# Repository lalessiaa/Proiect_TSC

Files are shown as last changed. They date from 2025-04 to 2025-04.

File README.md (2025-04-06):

# Open book reader
Am proiectat un E-book reader, fiind construit in jurul microcontrolerului ESP32-C6, cu un incarcator USB-C si slot microSD.

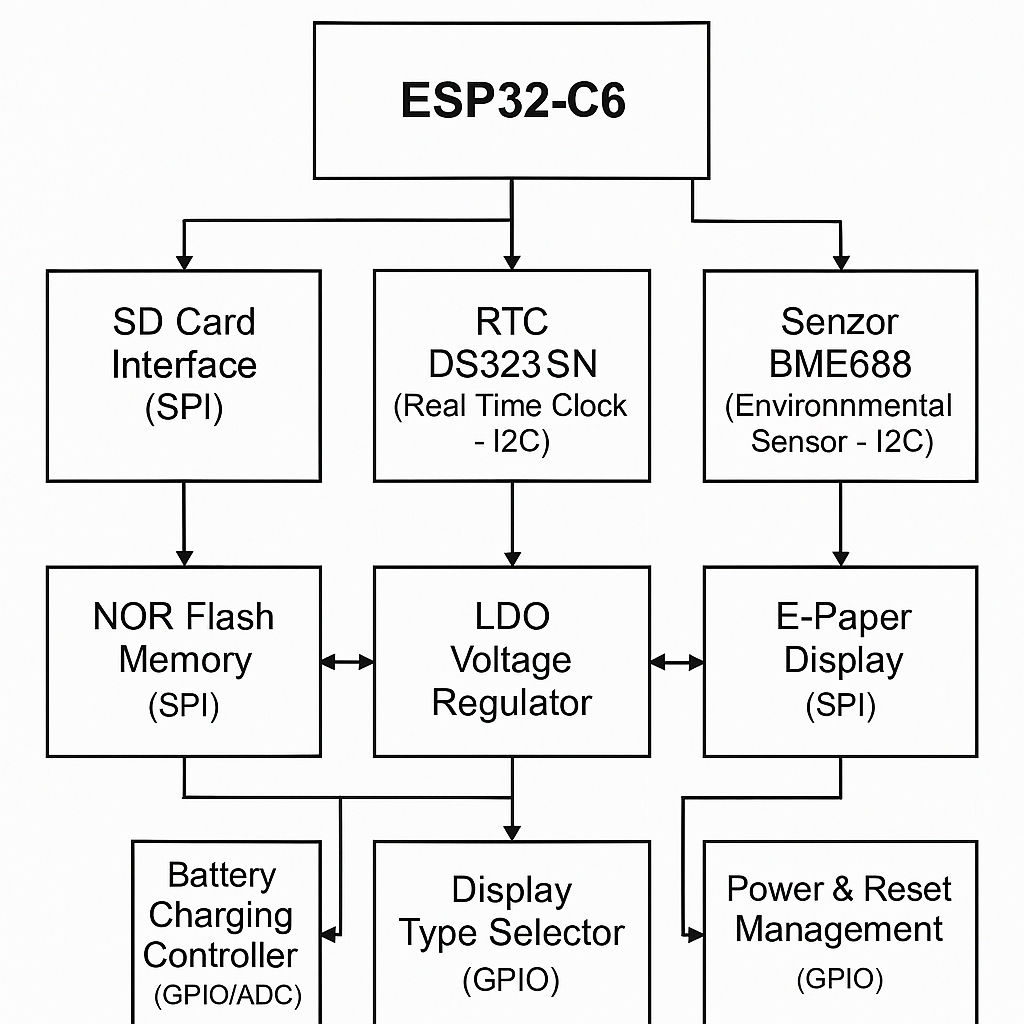
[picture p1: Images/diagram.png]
Diagrama openbook


Am urmat mai multi pasi in realizarea acestui poriect:
-	Crearea schematicului 
-	Am plasat componentele pe PCB
-	Am tras circuite si rutele
-	Incarcarea elementelor 3D pe PCB
-	Crearea bateriei si a display-ului
-	Inserarea bateriei, display-ului si a PCB-ului incarcasa 3D
  
# Functionalitati hardware
## ESP32-C6 
Este microcontroller-ul , el controleaza toate componentele si gestioneaza datele.
El foloseste mai multi pini printre care :
1)	Pentru comunicarea SPI cu viteza mare si numar redus de pini avem ( card SD ):   IO6 , IO7 (MOSI) , IO10 (CS) 
2)	Pentru a intra in mod de resetare rapida si mod de programare : IO0 - Buton BOOT , IO3 - Buton Reset
3)	External NOR Flash 64MB (SPI) pentru a extinde memoria: IO2 (MISO) , IO4 (CS) , IO6 (CLK/SCK) , IO7 (MOSI) 
4)	Battery Charge Level (GPIO) : IO12 

5)	Display Type Selector (GPIO): IO14

6)	Environmental Sensor BME688 (I2C) : IO8 (SCL), IO9 (SDA) 
7)	RTC Module DS3231SN (I2C) : IO8 (SCL) - linie de ceas I2C
IO9 (SDA) - linie de date I2C
8)	EPD Power (SPI) : IO6 (CLK/SCK), IO7 (MOSI), IO2 (MISO), IO5 (CS) 

1.	Senzorul de Mediu BME688
o	Interfață: I2C
o	Măsoară temperatura, umiditatea, presiunea, și compușii volatili organici pentru monitorizarea calității aerului.
2.	Memorie Externă NOR Flash 64MB
o	Interfață: SPI
o	Descriere: Folosită pentru stocarea datelor extinse și codului care nu se încadrează în memoria internă a ESP32.
o	Are consum redus în modul standby, crescând în timpul accesărilor de date.
3.	RTC (Real Time Clock) DS3231SN
o	Interfață: I2C
o	Menține timpul real chiar și în absența alimentării principale, utilizând o baterie de backup.
4.	Modulul de Încărcare a Bateriei
o	Interfață: GPIO (pentru monitorizarea stării)
o	Gestionează încărcarea bateriei Li-Po asigurând încărcare sigură și eficientă.
o	Are un consum mic, dependent de starea bateriei și de modul de încărcare.
5.	Regulator de Tensiune LDO
o	Regulează tensiunea de intrare pentru a asigura o alimentare stabilă de 3.3V pentru toate componentele.
Comunicații și Procesare
•	SPI: Utilizat pentru comunicații rapide cu memoria flash și display-ul E-Paper. Acest protocol este ideal pentru transferul de date la viteze înalte, esențial pentru performanța display-ului și accesul rapid la date.
•	I2C: Folosit pentru comunicația cu senzori de mediu și modulul RTC, care nu necesită viteze mari de transfer dar beneficiază de simplificarea conexiunilor.

# Bill of Materials
| Componenta | Link | Datasheet
| --- | --- |---|
|ESP32_WROVER_SPARKFUN-DISCRETESEMI_MOSFET_PCH-DMG2305UX-7|https://componentsearchengine.com/part-view/DMG2305UX-7/Diodes%20Incorporated|https://www.diodes.com//assets/Datasheets/DMG2305UX.pdf|
| QWIIC_CONNECTORJS-1MM | https://www.snapeda.com/parts/PRT-14417/SparkFun/view-part/ |https://www.snapeda.com/parts/PRT-14417/SparkFun%20Electronics/datasheet/
|CPH3225A|https://www.snapeda.com/parts/CPH3225A/Seiko+Instruments/view-part/?ref=eda|https://www.snapeda.com/parts/CPH3225A/Seiko%20Instruments/datasheet/|
|BUTTON_CUSYOMV1|https://industry.panasonic.com/global/en/downloads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|https://industry.panasonic.com/global/en/downloads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
|ESP32_WROVER_EAGLE-LTSPICE_CC0402|https://componentsearchengine.com/part-view/CC0402MRX5R5BB106/YAGEO|https://componentsearchengine.com/Datasheets/2/CC0402MRX5R5BB106.pdf
| ESP32_WROVER_EAGLE-LTSPICE_RR0402  | https://www.snapeda.com/parts/RC0402FR-07226RL/Yageo/view-part/ |https://www.snapeda.com/parts/RC0402FR-07226RL/Yageo/datasheet/
|BD5229G-TR|https://componentsearchengine.com/part-view/BD5229G-TR/ROHM%20Semiconductor|https://datasheet.datasheetarchive.com/originals/distributors/Datasheets_SAMA/f2b9741ef86007909f138d561a359946.pdf|
|DS3231SN|https://www.snapeda.com/parts/DS3231SN%23/Analog+Devices/view-part/?ref=eda|https://www.snapeda.com/parts/DS3231SN%23/Analog%20Devices/datasheet/|
|112A-TAAR-R03_ATTEND|https://store.comet.bg/en/Catalogue/Product/43497/|https://store.comet.bg/en/Catalogue/Product/43497/|
|744043680IND_4828-WE-TPC_WRE|https://www.digikey.sg/en/models/1638515|https://www.we-online.com/components/products/datasheet/744043680.pdf
|ESP32-C6-WROOM-1-N8|https://www.snapeda.com/parts/ESP32-C6-WROOM-1-N8/Espressif+Systems/view-part/?ref=eda|https://www.snapeda.com/parts/ESP32-C6-WROOM-1-N8/Espressif%20Systems/datasheet/
|ADAFRUIT_LEDCHIP-LED0603|https://www.snapeda.com/parts/KP-1608SURCK/Kingbright/view-part/?ref=search&t=LED%200603|https://www.snapeda.com/parts/KP-1608SURCK/Kingbright/datasheet/
|MCP73831|https://www.digikey.com/en/models/1874108|https://ww1.microchip.com/downloads/aemDocuments/documents/APID/ProductDocuments/DataSheets/MCP73831-Family-Data-Sheet-DS20001984H.pdf|
|XC6220A331MR-G|https://componentsearchengine.com/part-view/XC6220A331MR-G/Torex|https://product.torexsemi.com/system/files/series/xc6220.pdf|
|ESP32_WROVER_EAGLE-LTSPICE_CC0402|https://componentsearchengine.com/Datasheets/2/CC0402MRX5R5BB106.pdf|https://componentsearchengine.com/part-view/CC0402MRX5R5BB106/YAGEO|
|ESP32C6_VARISTORCN1812|https://www.mouser.co.uk/ProductDetail/EPCOS-TDK/B72520T0350K062?qs=dEfas%2FXlABIszF52uu7vrg%3D%3D|https://www.tdk-electronics.tdk.com/inf/75/db/CTVS_14/Surge_protection_series.pdf|
|MAX17048G+T10|https://www.snapeda.com/parts/MAX17048G+T10/Analog+Devices/view-part/?ref=eda|https://www.snapeda.com/parts/MAX17048G+T10/Analog%20Devices/datasheet/|
|PGB1010603MR|https://www.snapeda.com/parts/PGB1010603MR/Littelfuse/view-part/?ref=eda|https://www.snapeda.com/parts/PGB1010603MR/Littelfuse%20Inc./datasheet/|
|RCL_CPOL-EUCT3528|https://ro.mouser.com/ProductDetail/Vishay-Sprague/TR3B106K025C1300?qs=jCGqFXxTmLdffnuDkXzk1g%3D%3D|https://www.vishay.com/docs/40080/tr3.pdf|
|FH34SRJ-24S-0.5SH_99_|https://componentsearchengine.com/part-view/XC6220A331MR-G/Torex|https://product.torexsemi.com/system/files/series/xc6220.pdf|
|SAMACSYS_PARTS_USB4110-GF-A|https://componentsearchengine.com/part-view/USB4110-GF-A/GCT%20(GLOBAL%20CONNECTOR%20TECHNOLOGY)|https://gct.co/files/drawings/usb4110.pdf|
|SI1308EDL-T1-GE3|https://componentsearchengine.com/part-view/SI1308EDL-T1-GE3/Vishay|https://componentsearchengine.com/Datasheets/1/SI1308EDL-T1-GE3.pdf|
|MBR0530|https://ro.mouser.com/ProductDetail/KYOCERA-AVX/SD0805S020S1R0?qs=jCA%252BPfw4LHbpkAoSnwrdjw%3D%3D|https://ro.mouser.com/datasheet/2/40/schottky-3165252.pdf|
|SJ|https://grabcad.com/library/solder-jumpers-1||
|W25Q512JVEIQ|https://www.snapeda.com/parts/W25Q512JVEIQ/Winbond+Electronics/view-part/?ref=eda|https://www.snapeda.com/parts/W25Q512JVEIQ/Winbond%20Electronics/datasheet/|
|ESP32_WROVER_BME680_BME680|https://www.snapeda.com/parts/BME680/Bosch/view-part/?welcome=home|https://www.snapeda.com/parts/BME680/Bosch%20Sensortec/datasheet/|
|CPH3225A|https://www.snapeda.com/parts/CPH3225A/Seiko+Instruments/view-part/?ref=eda|https://www.snapeda.com/parts/CPH3225A/Seiko%20Instruments/datasheet/|
|USBLC6-2SC6Y|https://www.snapeda.com/parts/USBLC6-2SC6Y/STMicroelectronics/view-part/?ref=eda|https://www.snapeda.com/parts/USBLC6-2SC6Y/STMicroelectronics/datasheet/|

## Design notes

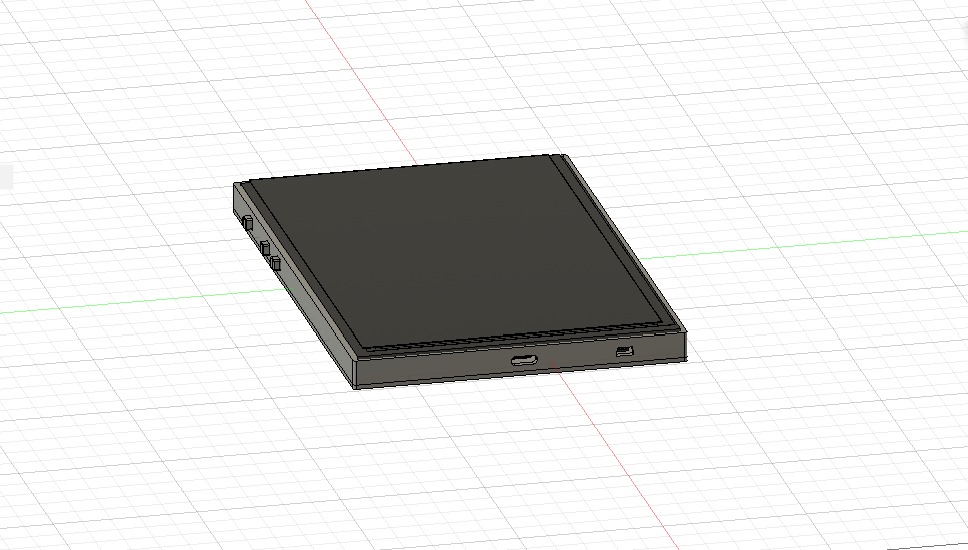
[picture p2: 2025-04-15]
Images/openbookdisplaynou.jpg

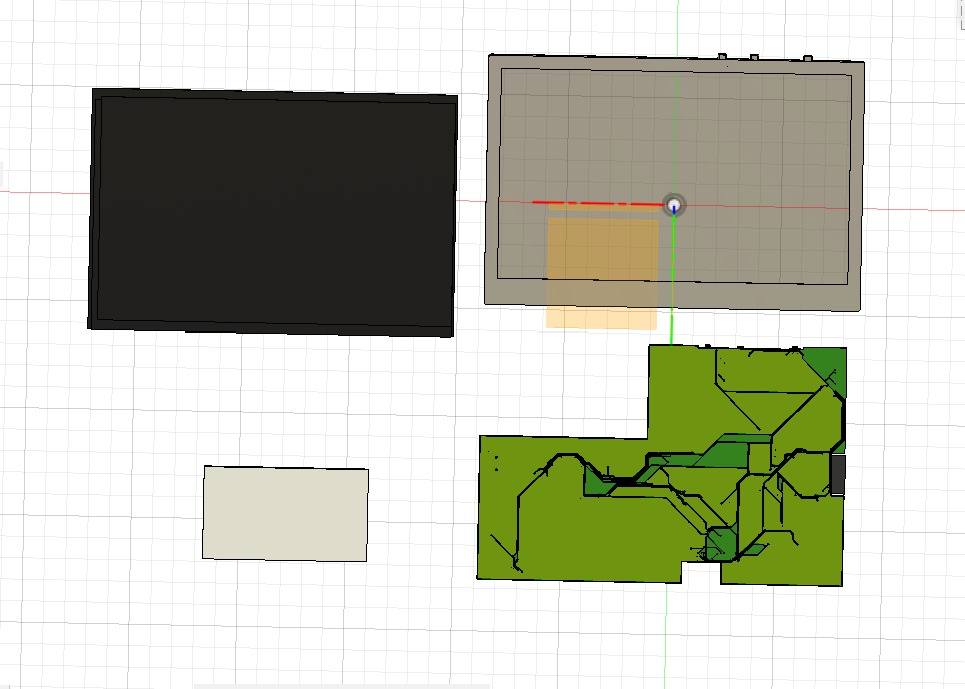
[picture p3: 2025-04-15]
Images/exploded_var_finala.jpg

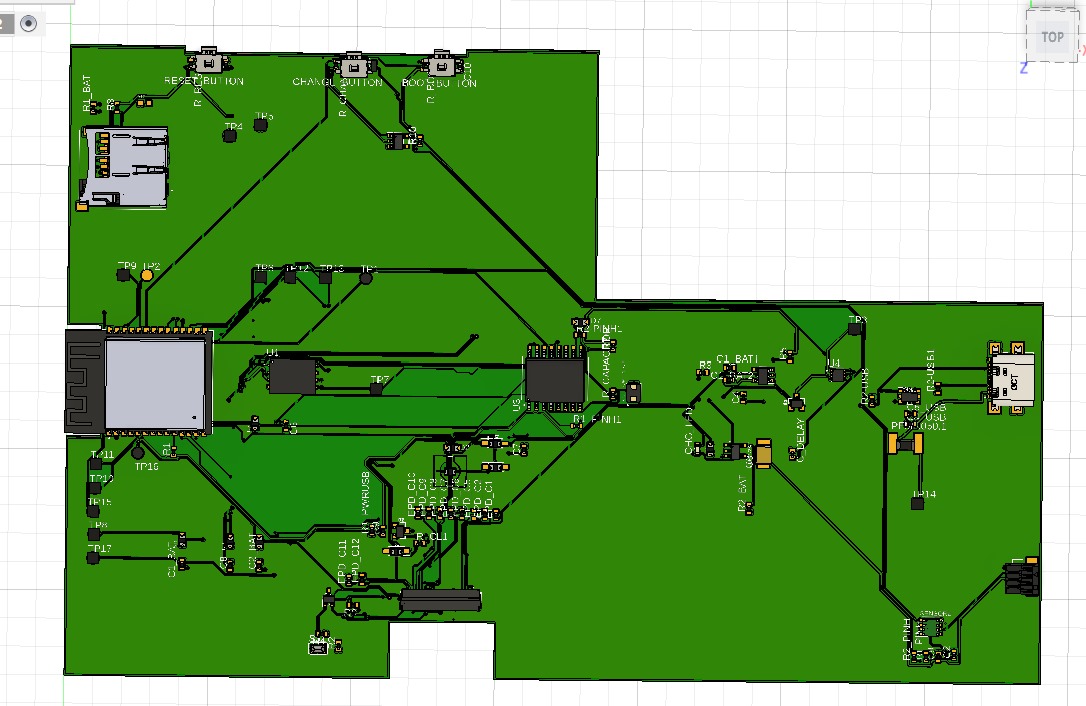
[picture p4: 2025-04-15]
Images/PCBvarfinala.jpg

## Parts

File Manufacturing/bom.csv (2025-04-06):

Qty | Value | Device | Package | Parts | Description | ARROW_PART_NUMBER | ARROW_PRICE-STOCK | AVAILABILITY | CENTROID_NOT_SPECIFIED | CHECK_PRICES | COPYRIGHT | DATASHEET | DESCRIPTION | DIGIKEY_DESCRIPTION | DIGIKEY_PART_NUMBER | HEIGHT | LEAD_FREE | MANUFACTURER_NAME | MANUFACTURER_PART_NUMBER | MF | MFR_NAME | MOUSER_PART_NUMBER | MOUSER_PRICE-STOCK | MOUSER_TESTING_PART_NUMBER | MOUSER_TESTING_PRICE-STOCK | MP | MPN | PACKAGE | POPULARITY | PREFIX | PRICE | PROD_ID | PURCHASE-URL | ROHS | SNAPEDA_LINK | SPICEMODEL | SPICEPREFIX | TEMPERATURE_RANGE_HIGH | TEMPERATURE_RANGE_LOW | TP_SIGNAL_NAME | VALUE
1 |  | ADAFRUIT_LEDCHIP-LED0603 | ADAFRUIT_CHIP-LED0603 | CHG_LED | LED
1 |  | SJ | SJ | SJ1 | SMD solder JUMPER |  |  |  |  |  |  |  |  |  |  |  |  |  |  |  |  |  |  |  |  |  |  |  | 3
1 | 0.47 | ESP32_WROVER_EAGLE-LTSPICE_RR0402 | ESP32_WROVER_EAGLE-LTSPICE_R0402 | R3 | RESISTOR, European symbol |  |  |  |  |  |  |  |  |  |  |  |  |  |  |  |  |  |  |  |  |  |  |  |  |  |  |  |  |  |  | NONE | R
1 | 01/Uf/50V | ESP32_WROVER_EAGLE-LTSPICE_CC0402 | ESP32_WROVER_EAGLE-LTSPICE_C0402 | EPD_C5 | CAPACITOR, European symbol |  |  |  |  |  |  |  |  |  |  |  |  |  |  |  |  |  |  |  |  |  |  |  |  |  |  |  |  |  |  | NONE | C
1 | 100k | ESP32_WROVER_EAGLE-LTSPICE_RR0402 | ESP32_WROVER_EAGLE-LTSPICE_R0402 | R1_PWRUSB | RESISTOR, European symbol |  |  |  |  |  |  |  |  |  |  |  |  |  |  |  |  |  |  |  |  |  |  |  |  |  |  |  |  |  |  | NONE | R
2 | 100nF | EAGLE-LTSPICE_CC0402 | EAGLE-LTSPICE_C0402 | C4_USB, C9 | CAPACITOR, European symbol |  |  |  |  |  |  |  |  |  |  |  |  |  |  |  |  |  |  |  |  |  |  |  |  |  |  |  |  |  |  | NONE | C
6 | 100nF | ESP32_WROVER_EAGLE-LTSPICE_CC0402 | ESP32_WROVER_EAGLE-LTSPICE_C0402 | C1, C2, C6, C8, C10, C_DELAY | CAPACITOR, European symbol |  |  |  |  |  |  |  |  |  |  |  |  |  |  |  |  |  |  |  |  |  |  |  |  |  |  |  |  |  |  | NONE | C
1 | 100uF TANT | RCL_CPOL-EUCT3528 | RCL_CT3528 | C3 | POLARIZED CAPACITOR, European symbol |  |  |  |  |  |  |  |  |  |  |  |  |  |  |  |  |  |  |  |  |  |  |  | 0 |  |  |  |  |  |  |  | C
7 | 10K | ESP32_WROVER_EAGLE-LTSPICE_RR0402 | ESP32_WROVER_EAGLE-LTSPICE_R0402 | R2_PINH, R4, RI_PINH, R_BOOT, R_CHANGE, R_CL1, R_RESET | RESISTOR, European symbol |  |  |  |  |  |  |  |  |  |  |  |  |  |  |  |  |  |  |  |  |  |  |  |  |  |  |  |  |  |  | NONE | R
9 | 10k | ESP32_WROVER_EAGLE-LTSPICE_RR0402 | ESP32_WROVER_EAGLE-LTSPICE_R0402 | R1, R1_PINH1, R2-PINH1, R5, R6, R7, R8, R9, R10 | RESISTOR, European symbol |  |  |  |  |  |  |  |  |  |  |  |  |  |  |  |  |  |  |  |  |  |  |  |  |  |  |  |  |  |  | NONE | R
1 | 10uF | ESP32_WROVER_EAGLE-LTSPICE_CC0402 | ESP32_WROVER_EAGLE-LTSPICE_C0402 | C7 | CAPACITOR, European symbol |  |  |  |  |  |  |  |  |  |  |  |  |  |  |  |  |  |  |  |  |  |  |  |  |  |  |  |  |  |  | NONE | C
1 | 112A-TAAR-R03_ATTEND | 112A-TAAR-R03_ATTEND | 112ATAARR03ATTEND | J4 | Micro SD Card Socket, Push-Push Type, Top Mount, SMT, H=1.83mm, 10u |  |  |  |  |  |  |  | Micro SD Card Socket | Push-Push Type | Top Mount | SMT | H=1.83mm | 10u |  |  | 1.9mm |  | ATTEND | 112A-TAAR-R03 ATTEND
1 | 15 | ESP32_WROVER_EAGLE-LTSPICE_RR0402 | ESP32_WROVER_EAGLE-LTSPICE_R0402 | R_CAPACITOR | RESISTOR, European symbol |  |  |  |  |  |  |  |  |  |  |  |  |  |  |  |  |  |  |  |  |  |  |  |  |  |  |  |  |  |  | NONE | R
1 | 1UF/50V | ESP32_WROVER_EAGLE-LTSPICE_CC0402 | ESP32_WROVER_EAGLE-LTSPICE_C0402 | EPD_C7 | CAPACITOR, European symbol |  |  |  |  |  |  |  |  |  |  |  |  |  |  |  |  |  |  |  |  |  |  |  |  |  |  |  |  |  |  | NONE | C
1 | 1Uf/50V | ESP32_WROVER_EAGLE-LTSPICE_CC0402 | ESP32_WROVER_EAGLE-LTSPICE_C0402 | EPD_C10 | CAPACITOR, European symbol |  |  |  |  |  |  |  |  |  |  |  |  |  |  |  |  |  |  |  |  |  |  |  |  |  |  |  |  |  |  | NONE | C
1 | 1uF | ESP32_WROVER_EAGLE-LTSPICE_CC0402 | ESP32_WROVER_EAGLE-LTSPICE_C0402 | C5 | CAPACITOR, European symbol |  |  |  |  |  |  |  |  |  |  |  |  |  |  |  |  |  |  |  |  |  |  |  |  |  |  |  |  |  |  | NONE | C
7 | 1uF/50V | ESP32_WROVER_EAGLE-LTSPICE_CC0402 | ESP32_WROVER_EAGLE-LTSPICE_C0402 | EPD_C1, EPD_C2, EPD_C6, EPD_C8, EPD_C9, EPD_C11, EPD_C12 | CAPACITOR, European symbol |  |  |  |  |  |  |  |  |  |  |  |  |  |  |  |  |  |  |  |  |  |  |  |  |  |  |  |  |  |  | NONE | C
1 | 2.2 | ESP32_WROVER_EAGLE-LTSPICE_RR0402 | ESP32_WROVER_EAGLE-LTSPICE_R0402 | R2 | RESISTOR, European symbol |  |  |  |  |  |  |  |  |  |  |  |  |  |  |  |  |  |  |  |  |  |  |  |  |  |  |  |  |  |  | NONE | R
1 | 200 | ESP32_WROVER_EAGLE-LTSPICE_RR0402 | ESP32_WROVER_EAGLE-LTSPICE_R0402 | R1_BAT | RESISTOR, European symbol |  |  |  |  |  |  |  |  |  |  |  |  |  |  |  |  |  |  |  |  |  |  |  |  |  |  |  |  |  |  | NONE | R
2 | 20V/4.2A/52mO/1.4W | ESP32_WROVER_SPARKFUN-DISCRETESEMI_MOSFET_PCH-DMG2305UX-7 | ESP32_WROVER_SPARKFUN-DISCRETESEMI_SOT23-3 | Q1, Q2 | P-channel MOSFETs |  |  |  |  |  |  |  |  |  |  |  |  |  |  |  |  |  |  |  |  |  |  |  |  |  |  | TRAN-14388 |  |  |  |  |  |  |  |  | 20V/4.2A/52mO/1.4W
1 | 2k | ESP32_WROVER_EAGLE-LTSPICE_RR0402 | ESP32_WROVER_EAGLE-LTSPICE_R0402 | R2_BAT | RESISTOR, European symbol |  |  |  |  |  |  |  |  |  |  |  |  |  |  |  |  |  |  |  |  |  |  |  |  |  |  |  |  |  |  | NONE | R
2 | 4.7uF | EAGLE-LTSPICE_CC0402 | EAGLE-LTSPICE_C0402 | C1_BAT1, C5_USB | CAPACITOR, European symbol |  |  |  |  |  |  |  |  |  |  |  |  |  |  |  |  |  |  |  |  |  |  |  |  |  |  |  |  |  |  | NONE | C
3 | 4.7uF | ESP32_WROVER_EAGLE-LTSPICE_CC0402 | ESP32_WROVER_EAGLE-LTSPICE_C0402 | C1_BAT, C1_BAT2, C2_BAT | CAPACITOR, European symbol |  |  |  |  |  |  |  |  |  |  |  |  |  |  |  |  |  |  |  |  |  |  |  |  |  |  |  |  |  |  | NONE | C
1 | 4.7uF/25V | ESP32_WROVER_EAGLE-LTSPICE_CC0402 | ESP32_WROVER_EAGLE-LTSPICE_C0402 | C4 | CAPACITOR, European symbol |  |  |  |  |  |  |  |  |  |  |  |  |  |  |  |  |  |  |  |  |  |  |  |  |  |  |  |  |  |  | NONE | C
2 | 5k1 | ESP32_WROVER_EAGLE-LTSPICE_RR0402 | ESP32_WROVER_EAGLE-LTSPICE_R0402 | R2-USB, R2-USB1 | RESISTOR, European symbol |  |  |  |  |  |  |  |  |  |  |  |  |  |  |  |  |  |  |  |  |  |  |  |  |  |  |  |  |  |  | NONE | R
1 | 68uH | 744043680IND_4828-WE-TPC_WRE | IND_4828-WE-TPC_WRE | L1 |  |  |  |  |  |  | Copyright (C) 2024 Ultra Librarian. All rights reserved. |  |  |  |  |  |  |  | 744043680 |  | Wurth Electronics
1 | BD5229G-TR | XC6220A331MR-G | SOT95P280X120-5N | IC1 | LDO Voltage Regulators |  |  |  |  |  |  |  | LDO Voltage Regulators |  |  | 1.2mm |  | Torex | XC6220A331MR-G |  |  | 865-XC6220A331MR-G | https://www.mouser.co.uk/ProductDetail/Torex-Semiconductor/XC6220A331MR-G?qs=AsjdqWjXhJ8ZSWznL1J0gg%3D%3D
1 | BME688 | ESP32_WROVER_BME680_BME680 | ESP32_WROVER_BME680_PSON80P300X300X100-8N | SENSOR2 | Integrated Environmental Unit |  |  | Unavailable |  |  |  |  | Integrated Environmental Unit |  |  |  |  |  |  | Bosch Sensortec |  |  |  |  |  | BME680 |  | LGA-8 Bosch Tools |  |  | None
3 | BUTTON_CUSYOMV1 | BUTTON_CUSYOMV1 | MYBUTTON | BOOT_BUTTON, CHANGE_BUTTON, RESET_BUTTON
1 | CPH3225A | CPH3225A | CAPCP3225X100N | C10_SUPERCAP | Cap 0.011F 3.3V 1210 Flat Check availability |  |  | Not in stock |  | https://www.snapeda.com/parts/CPH3225A/Seiko+Instruments/view-part/?ref=eda |  |  | 11 mF (EDLC) Supercapacitor 3.3 V 1210 (3225 Metric) - - |  |  |  |  |  |  | Seiko Instruments |  |  |  |  |  | CPH3225A |  | 1210 Seiko |  |  | None |  | https://www.snapeda.com/api/url_track_click_mouser/?unipart_id=562593&manufacturer=Seiko Instruments&part_name=CPH3225A&search_term=None |  | https://www.snapeda.com/parts/CPH3225A/Seiko+Instruments/view-part/?ref=snap
1 | DS3231SN# | DS3231SN# | SOIC127P1032X265-16N | U3 | Real Time Clock Serial 16-Pin SOIC W T/R Check availability |  |  | In Stock |  | https://www.snapeda.com/parts/DS3231SN%23/Analog+Devices/view-part/?ref=eda |  |  | Extremely Accurate I²C-Integrated RTC/TCXO/Crystal |  |  |  |  |  |  | Analog Devices |  |  |  |  |  | DS3231SN# |  | SOIC-16 Maxim |  |  | None |  | https://www.snapeda.com/api/url_track_click_mouser/?unipart_id=99048&manufacturer=Analog Devices&part_name=DS3231SN#&search_term=None |  | https://www.snapeda.com/parts/DS3231SN%23/Analog+Devices/view-part/?ref=snap
1 | ESP32-C6-WROOM-1-N8 | ESP32-C6-WROOM-1-N8 | XCVR_ESP32-C6-WROOM-1-N8 | U2 | Check availability |  |  | In Stock |  | https://www.snapeda.com/parts/ESP32-C6-WROOM-1-N8/Espressif+Systems/view-part/?ref=eda |  |  | Multiprotocol Modules ESP32-C6 module | Wi-Fi 6 in 2.4 GHz band | Bluetooth 5 | Zigbee 3.0 and Thread. ESP34-WROOM Compatible - ENGINEERING SAMPLE |  |  |  |  |  |  | Espressif Systems |  |  |  |  |  | ESP32-C6-WROOM-1-N8 |  | None |  |  | None |  |  |  | https://www.snapeda.com/parts/ESP32-C6-WROOM-1-N8/Espressif+Systems/view-part/?ref=snap
1 | ESP32C6_VARISTORCN1812 | ESP32C6_VARISTORCN1812 | ESP32C6_VARISTOR_CT/CN1812 | PFMF.050.1 | VARISTOR |  |  |  |  |  |  |  |  |  |  |  |  |  |  |  |  |  |  |  |  |  |  |  | 0
2 | ESP32_WROVER_AVX---SD0805S020S1R0_AVX_SD0805S020S1R0_0_0AVX_SD0805S020S1R0_0_0 | ESP32_WROVER_AVX---SD0805S020S1R0_AVX_SD0805S020S1R0_0_0AVX_SD0805S020S1R0_0_0 | ESP32_WROVER_AVX---SD0805S020S1R0_AVX_SD0805S020S1R0_0 | D2, D7 | Schottky Barrier Rectifier Diode |  |  |  | No |  |  | http://datasheets.avx.com/schottky.pdf |  | DIODE SCHOTTKY 20V 1A 0805 | 478-7800-1-ND |  | yes |  |  | AVX |  | 581-SD0805S020S1R0 |  |  |  |  |  | 0805 (2012 metric) |  | D |  |  |  | yes |  |  |  | +125°C | -55°C
1 | ESP32_WROVER_SPARKFUN-IC-POWER_MCP73831 | ESP32_WROVER_SPARKFUN-IC-POWER_MCP73831 | ESP32_WROVER_SPARKFUN-IC-POWER_SOT23-5 | MCP73831 | MCP73831T Li-Ion, Li-Pol Controller |  |  |  |  |  |  |  |  |  |  |  |  |  |  |  |  |  |  |  |  |  |  |  |  |  |  | IC-09995
1 | FH34SRJ-24S-0.5SH_99_ | FH34SRJ-24S-0.5SH_99_ | FH34SRJ24S05SH99 | J1 | (0.50mm) Surface Mount, Right Angle |  |  |  |  |  |  |  | 24 Position FFC | FPC Connector Contacts | (0.50mm) Surface Mount | Right Angle |  |  | 1.1mm |  | Hirose | FH34SRJ-24S-0.5SH(99) |  |  | 798-FH34SRJ24S05SH99 | https://www.mouser.co.uk/ProductDetail/Hirose-Connector/FH34SRJ-24S-0.5SH99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
1 | MAX17048G+T10 | MAX17048G+T10 | SON50P200X200X80-9N | U4 | Check availability |  |  | In Stock |  | https://www.snapeda.com/parts/MAX17048G+T10/Analog+Devices/view-part/?ref=eda |  |  | 3µA 1-Cell/2-Cell Fuel Gauge with ModelGauge |  |  |  |  |  |  | Analog Devices |  |  |  |  |  | MAX17048G+T10 |  | TDFN-8 Maxim |  |  | None |  | https://www.snapeda.com/api/url_track_click_mouser/?unipart_id=329239&manufacturer=Analog Devices&part_name=MAX17048G+T10&search_term=None |  | https://www.snapeda.com/parts/MAX17048G+T10/Analog+Devices/view-part/?ref=snap
3 | MBR0530 | MBR0530 | SOD3716X135N | D3, D4, D5 | ON SEMICONDUCTOR - MBR0530 - DIODE, SCHOTTKY, 0.5A, 30V, SOD-123 |  |  | In Stock |  | https://www.snapeda.com/parts/MBR0530/Onsemi/view-part/?ref=eda |  |  | Diode Schottky 30 V 500mA Surface Mount SOD-123 |  |  |  |  |  |  | ON Semiconductor |  |  |  |  |  | MBR0530 |  | SOD-123-2 ON Semiconductor |  |  | None |  | https://www.snapeda.com/api/url_track_click_mouser/?unipart_id=179458&manufacturer=ON Semiconductor&part_name=MBR0530&search_term=None |  | https://www.snapeda.com/parts/MBR0530/Onsemi/view-part/?ref=snap
6 | PGB1010603MR | PGB1010603MR | DIOC1608X36N | D6, D8, D9, D10, D11, D12 | Check availability |  |  | In Stock |  | https://www.snapeda.com/parts/PGB1010603MR/Littelfuse/view-part/?ref=eda |  |  | 150V (Typ) Clamp - Ipp Tvs Diode Surface Mount 0603 (1608 Metric) |  |  |  |  |  |  | Littelfuse Inc. |  |  |  |  |  | PGB1010603MR |  | 0603 Littelfuse Inc. |  |  | None |  | https://www.snapeda.com/api/url_track_click_mouser/?unipart_id=5659453&manufacturer=Littelfuse Inc.&part_name=PGB1010603MR&search_term=None |  | https://www.snapeda.com/parts/PGB1010603MR/Littelfuse/view-part/?ref=snap
1 | QWIIC_RIGHT_ANGLE | QWIIC_CONNECTORJS-1MM | JST04_1MM_RA | J3 | SparkFun I2C Standard Qwiic Connector |  |  |  |  |  |  |  |  |  |  |  |  |  |  |  |  |  |  |  |  |  |  |  |  |  |  | CONN-13694 |  |  |  |  |  |  |  |  | QWIIC_RIGHT_ANGLE
1 | SAMACSYS_PARTS_USB4110-GF-A | SAMACSYS_PARTS_USB4110-GF-A | SAMACSYS_PARTS_USB4110GFA | J2 | CONN USB 2.0 TYPE-C R/A SMT |  |  |  |  |  |  |  | CONN USB 2.0 TYPE-C R/A SMT |  |  | 3.26mm |  | GCT (GLOBAL CONNECTOR TECHNOLOGY) | USB4110-GF-A |  |  | 640-USB4110-GF-A | https://www.mouser.co.uk/ProductDetail/GCT/USB4110-GF-A?qs=KUoIvG%2F9IlYiZvIXQjyJeA%3D%3D
1 | SI1308EDL-T1-GE3 | SI1308EDL-T1-GE3 | SOT65P210X110-3N | Q3 | MOSFET N-Ch 30V 1.5A TrenchFET SC70 Vishay Si1308EDL-T1-GE3 N-channel MOSFET Transistor, 1.5 A, 30 V, 3-Pin SC-70 |  |  | In Stock |  | https://www.snapeda.com/parts/SI1308EDL-T1-GE3/Vishay+Siliconix/view-part/?ref=eda |  |  | Si1308EDL-T1-GE3 N-channel MOSFET Transistor | 1.5 A | 30 V | 3-Pin SC-70 | Siliconix / Vishay SI1308EDL-T1-GE3 |  |  |  |  |  |  | Vishay Siliconix |  |  |  |  |  | SI1308EDL-T1-GE3 |  | SOT-323 Vishay Semiconductor |  |  | None |  | https://www.snapeda.com/api/url_track_click_mouser/?unipart_id=274603&manufacturer=Vishay Siliconix&part_name=SI1308EDL-T1-GE3&search_term=None |  | https://www.snapeda.com/parts/SI1308EDL-T1-GE3/Vishay+Siliconix/view-part/?ref=snap
17 | TPTP20R | TPTP20R | TP20R | TP1, TP2, TP3, TP4, TP5, TP6, TP7, TP8, TP9, TP10, TP11, TP12, TP13, TP14, TP15, TP16, TP17 | Test pad |  |  |  |  |  |  |  |  |  |  |  |  |  |  |  |  |  |  |  |  |  |  |  | 2
1 | USBLC6-2SC6Y | USBLC6-2SC6Y | SOT95P280X145-6N | D1 | Low Cap. ESD Protection Auto SOT-23-6 STMicroelectronics USBLC6-2SC6Y, Dual Uni-Directional TVS Diode Array, 6-Pin SOT-23 |  |  | In Stock |  | https://www.snapeda.com/parts/USBLC6-2SC6Y/STMicroelectronics/view-part/?ref=eda |  |  | 17V Clamp 5A (8/20µs) Ipp Tvs Diode Surface Mount SOT-23-6 |  |  |  |  |  |  | STMicroelectronics |  |  |  |  |  | USBLC6-2SC6Y |  | SOT-23-6 STMicroelectronics |  |  | None |  |  |  | https://www.snapeda.com/parts/USBLC6-2SC6Y/STMicroelectronics/view-part/?ref=snap
1 | W25Q512JVEIQ | W25Q512JVEIQ | SON127P600X800X80-9N | U1 | Check availability |  |  | In Stock |  | https://www.snapeda.com/parts/W25Q512JVEIQ/Winbond+Electronics/view-part/?ref=eda |  |  | FLASH - NOR Memory IC 512Mb (64M x 8) SPI - Quad I/O 133 MHz 8-WSON (8x6) |  |  |  |  |  |  | Winbond Electronics |  |  |  |  |  | W25Q512JVEIQ |  | Package |  |  | None |  |  |  | https://www.snapeda.com/parts/W25Q512JVEIQ/Winbond+Electronics/view-part/?ref=snap
1 | XC6220A331MR-G | XC6220A331MR-G | SOT95P280X120-5N | IC4 | LDO Voltage Regulators |  |  |  |  |  |  |  | LDO Voltage Regulators |  |  | 1.2mm |  | Torex | XC6220A331MR-G |  |  | 865-XC6220A331MR-G | https://www.mouser.co.uk/ProductDetail/Torex-Semiconductor/XC6220A331MR-G?qs=AsjdqWjXhJ8ZSWznL1J0gg%3D%3D

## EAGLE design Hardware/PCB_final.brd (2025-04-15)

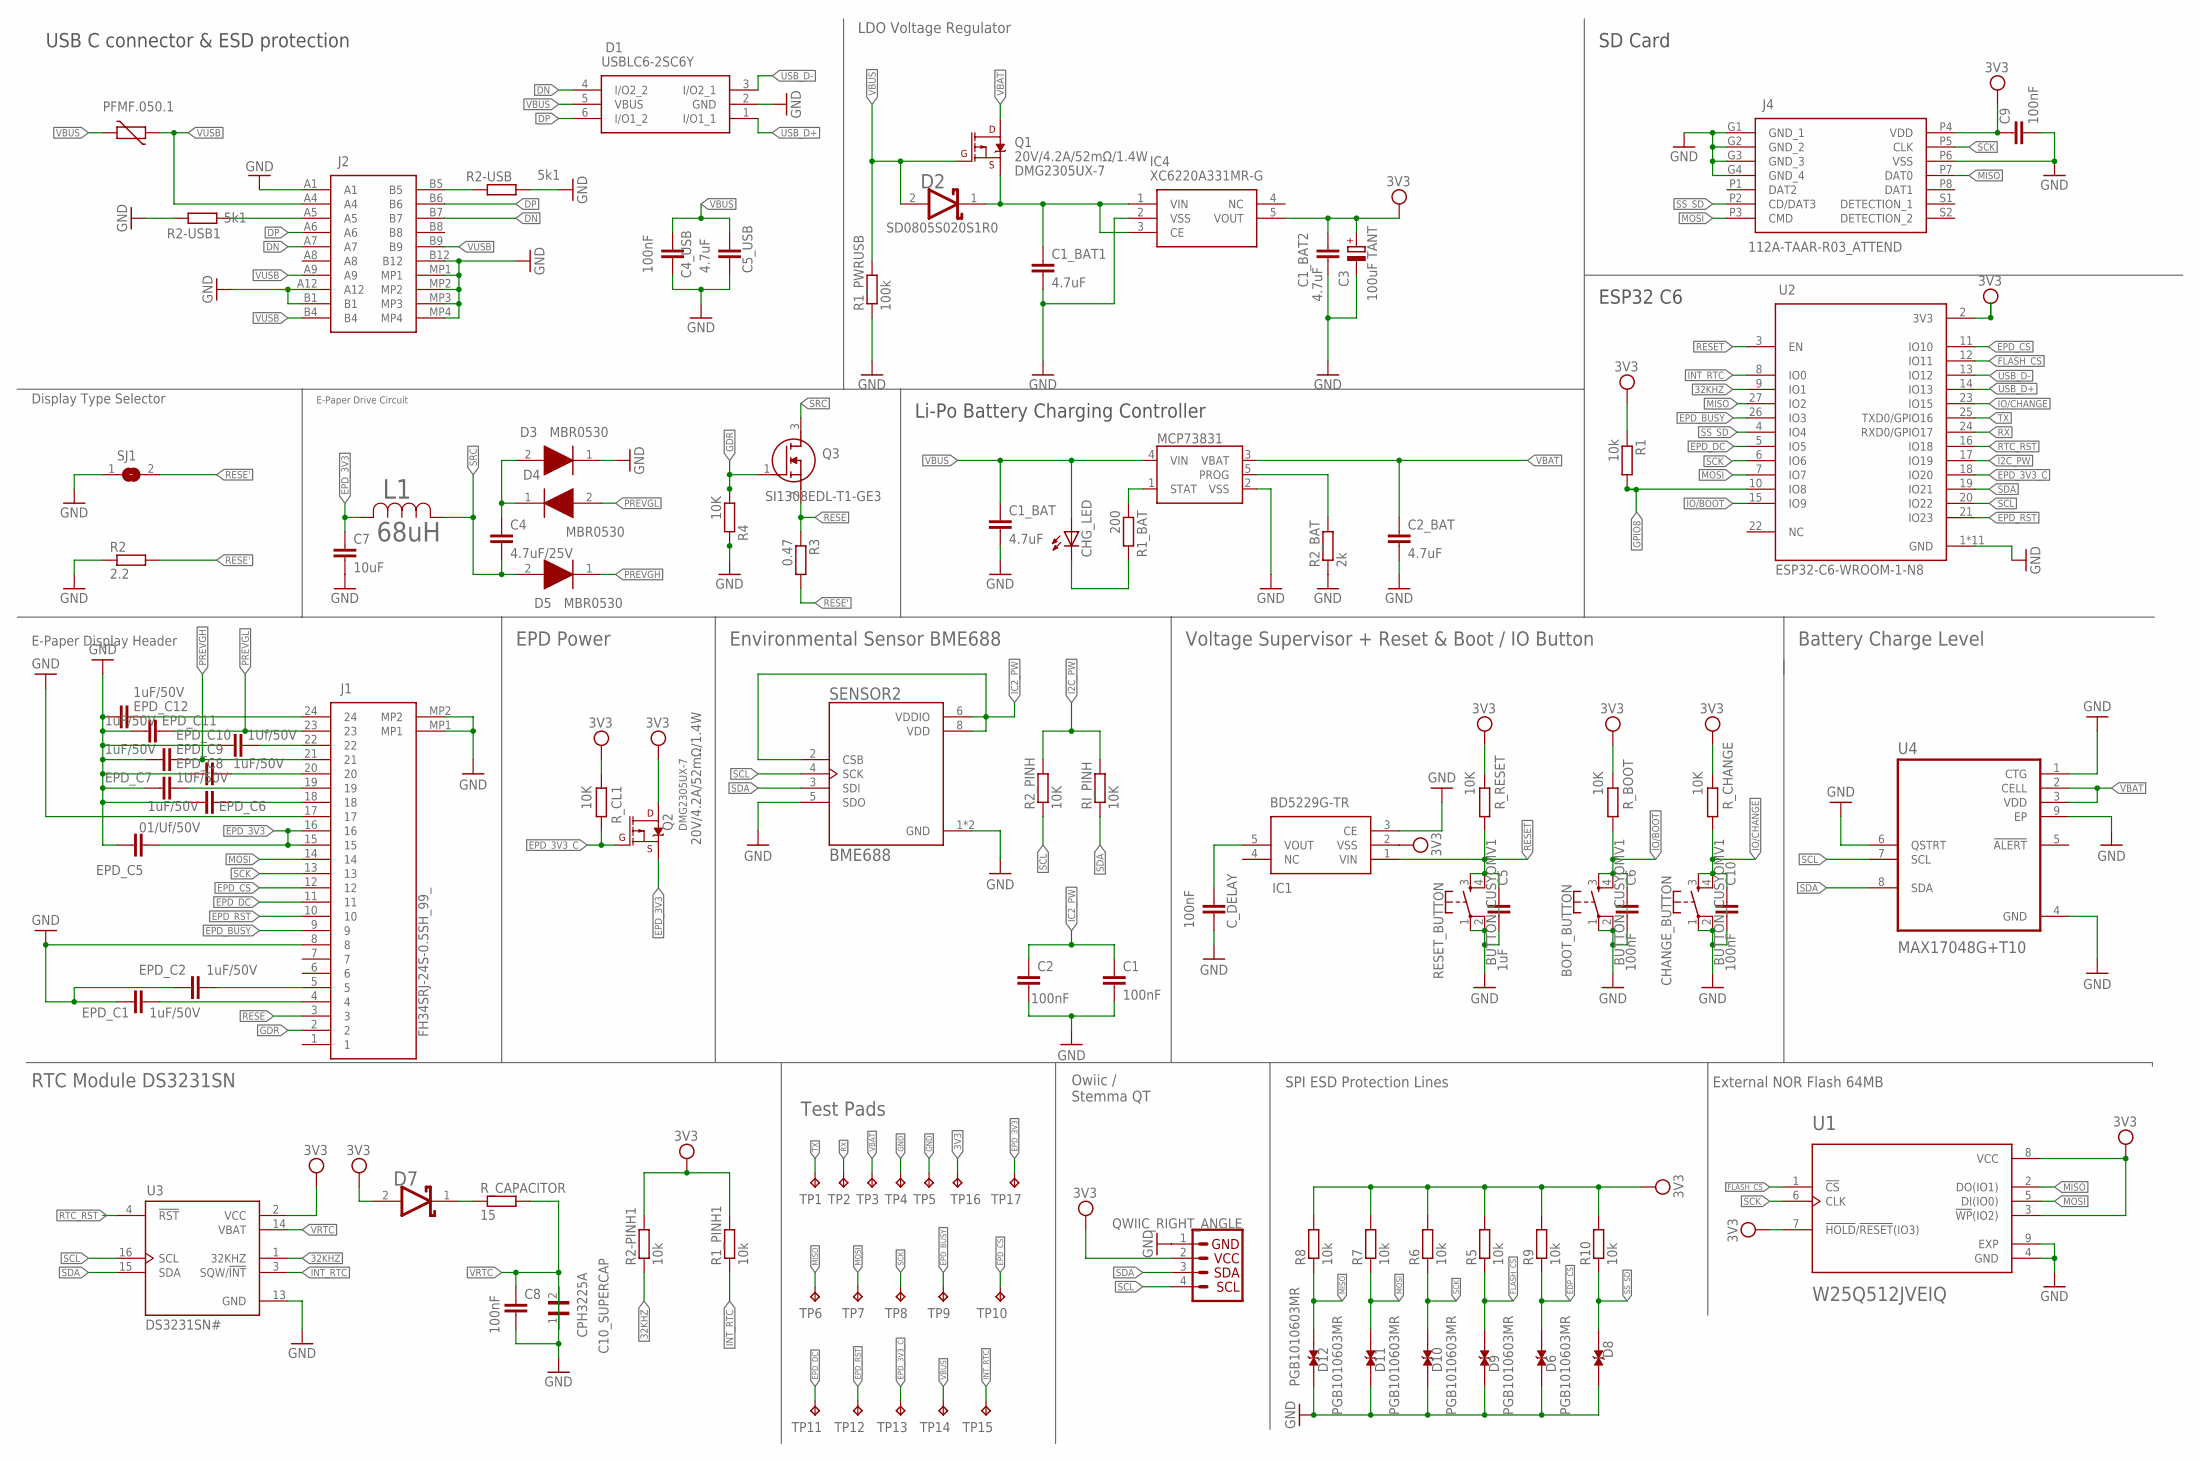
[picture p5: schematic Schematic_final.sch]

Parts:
BOOT_BUTTON: BUTTON_CUSYOMV1; MYBUTTON
C1, C2, C6, C8, C10: 100nF; ESP32_WROVER_EAGLE-LTSPICE_C0402
C1_BAT, C1_BAT2, C2_BAT: 4.7uF; ESP32_WROVER_EAGLE-LTSPICE_C0402
C1_BAT1, C5_USB: 4.7uF; EAGLE-LTSPICE_C0402
C3: 100uF TANT; RCL_CT3528
C4: 4.7uF/25V; ESP32_WROVER_EAGLE-LTSPICE_C0402
C4_USB, C9: 100nF; EAGLE-LTSPICE_C0402
C5: 1uF; ESP32_WROVER_EAGLE-LTSPICE_C0402
C7: 10uF; ESP32_WROVER_EAGLE-LTSPICE_C0402
C10_SUPERCAP: CPH3225A; CAPCP3225X100N
CHANGE_BUTTON: BUTTON_CUSYOMV1; MYBUTTON
CHG_LED: ADAFRUIT_LEDCHIP-LED0603; ADAFRUIT_CHIP-LED0603
C_DELAY: 100nF; ESP32_WROVER_EAGLE-LTSPICE_C0402
D1: USBLC6-2SC6Y; SOT95P280X145-6N
D2, D7: ESP32_WROVER_AVX---SD0805S020S1R0_AVX_SD0805S020S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; ESP32_WROVER_AVX---SD0805S020S1R0_AVX_SD0805S020S1R0_0
D3, D4, D5: MBR0530; SOD3716X135N
D6, D8, D9, D10, D11, D12: PGB1010603MR; DIOC1608X36N
EPD_C1, EPD_C2, EPD_C6, EPD_C8, EPD_C9, EPD_C11, EPD_C12: 1uF/50V; ESP32_WROVER_EAGLE-LTSPICE_C0402
EPD_C5: 01/Uf/50V; ESP32_WROVER_EAGLE-LTSPICE_C0402
EPD_C7: 1UF/50V; ESP32_WROVER_EAGLE-LTSPICE_C0402
EPD_C10: 1Uf/50V; ESP32_WROVER_EAGLE-LTSPICE_C0402
IC1: BD5229G-TR; SOT95P280X120-5N
IC4: XC6220A331MR-G; SOT95P280X120-5N
J1: FH34SRJ-24S-0.5SH_99_; FH34SRJ24S05SH99
J2: SAMACSYS_PARTS_USB4110-GF-A; SAMACSYS_PARTS_USB4110GFA
J3: QWIIC_RIGHT_ANGLE; JST04_1MM_RA
J4: 112A-TAAR-R03_ATTEND; 112ATAARR03ATTEND
L1: 68uH; IND_4828-WE-TPC_WRE
MCP73831: ESP32_WROVER_SPARKFUN-IC-POWER_MCP73831; ESP32_WROVER_SPARKFUN-IC-POWER_SOT23-5
PFMF.050.1: ESP32C6_VARISTORCN1812; ESP32C6_VARISTOR_CT/CN1812
Q1, Q2: 20V/4.2A/52mΩ/1.4W; ESP32_WROVER_SPARKFUN-DISCRETESEMI_SOT23-3
Q3: SI1308EDL-T1-GE3; SOT65P210X110-3N
R1, R1_PINH1, R2-PINH1, R5, R6, R7, R8, R9, R10: 10k; ESP32_WROVER_EAGLE-LTSPICE_R0402
R1_BAT: 200; ESP32_WROVER_EAGLE-LTSPICE_R0402
R1_PWRUSB: 100k; ESP32_WROVER_EAGLE-LTSPICE_R0402
R2: 2.2; ESP32_WROVER_EAGLE-LTSPICE_R0402
R2-USB, R2-USB1: 5k1; ESP32_WROVER_EAGLE-LTSPICE_R0402
R2_BAT: 2k; ESP32_WROVER_EAGLE-LTSPICE_R0402
R2_PINH, R4: 10K; ESP32_WROVER_EAGLE-LTSPICE_R0402
R3: 0.47; ESP32_WROVER_EAGLE-LTSPICE_R0402
RESET_BUTTON: BUTTON_CUSYOMV1; MYBUTTON
RI_PINH: 10K; ESP32_WROVER_EAGLE-LTSPICE_R0402
R_BOOT: 10K; ESP32_WROVER_EAGLE-LTSPICE_R0402
R_CAPACITOR: 15; ESP32_WROVER_EAGLE-LTSPICE_R0402
R_CHANGE: 10K; ESP32_WROVER_EAGLE-LTSPICE_R0402
R_CL1: 10K; ESP32_WROVER_EAGLE-LTSPICE_R0402
R_RESET: 10K; ESP32_WROVER_EAGLE-LTSPICE_R0402
SENSOR2: BME688; ESP32_WROVER_BME680_PSON80P300X300X100-8N
SJ1: SJ
TP1, TP2, TP3, TP4, TP5, TP6, TP7, TP8, TP9, TP10, TP11, TP12, TP13, TP14, TP15, TP16, TP17: TPTP20R; TP20R
U1: W25Q512JVEIQ; SON127P600X800X80-9N
U2: ESP32-C6-WROOM-1-N8; XCVR_ESP32-C6-WROOM-1-N8
U3: DS3231SN#; SOIC127P1032X265-16N
U4: MAX17048G+T10; SON50P200X200X80-9N

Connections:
3V3: C1_BAT2.1, C3.+, C9.1, D7.2 (ANODE), IC1.2 (VSS), IC4.5 (VOUT), J3.2, J4.P4 (VDD), Q2.3 (D), R1.1, R1_PINH1.2, R2-PINH1.2, R5.2, R6.2, R7.2, R8.2, R9.2, R10.2, R_BOOT.2, R_CHANGE.2, R_CL1.2, R_RESET.2, TP16.TP, U1.3 (!WP!(IO2)), U1.7 (!HOLD!/!RESET!(IO3)), U1.8 (VCC), U2.2 (3V3), U3.2 (VCC)
32KHZ: R2-PINH1.1, U2.9 (IO1), U3.1 (32KHZ)
DN: J2.A7
DP: J2.A6
EDP_CS: D9.2, R9.1
EPD_3V3: C7.1, EPD_C5.2, J1.15, J1.16, L1.2, Q2.2 (S), TP17.TP
EPD_3V3_C: Q2.1 (G), R_CL1.1, TP13.TP, U2.18 (IO20)
EPD_BUSY: J1.9, TP9.TP, U2.26 (IO3)
EPD_CS: J1.12, TP10.TP, U2.11 (IO10)
EPD_DC: J1.11, TP11.TP, U2.5 (IO5)
EPD_RST: J1.10, TP12.TP, U2.21 (IO23)
FLASH_CS: D10.2, R5.1, U1.1 (!CS), U2.12 (IO11)
GDR: J1.2, Q3.1 (G), R4.2
GND: BOOT_BUTTON.1, BOOT_BUTTON.2, C1.2, C1_BAT.2, C1_BAT1.2, C1_BAT2.2, C2.2, C2_BAT.2, C3.-, C4_USB.2, C5.2, C5_USB.2, C6.2, C7.2, C8.2, C9.2, C10.2, C10_SUPERCAP.2, CHANGE_BUTTON.1, CHANGE_BUTTON.2, C_DELAY.2, D1.2 (GND), D3.1 (K), D6.1, D8.1, D9.1, D10.1, D11.1, D12.1, EPD_C1.1, EPD_C2.1, EPD_C5.1, EPD_C6.2, EPD_C7.2, EPD_C8.2, EPD_C9.2, EPD_C10.2, EPD_C11.2, EPD_C12.2, IC1.3 (CE), IC4.2 (VSS), J1.8, J1.17, J1.MP1, J1.MP2, J2.A1, J2.A12, J2.B1, J2.B12, J2.MP1, J2.MP2, J2.MP3, J2.MP4, J3.1, J4.G1 (GND_1), J4.G2 (GND_2), J4.G3 (GND_3), J4.G4 (GND_4), J4.P6 (VSS), MCP73831.2 (VSS), R1_PWRUSB.1, R2.1, R2-USB.2, R2-USB1.1, R2_BAT.1, R4.1, RESET_BUTTON.1, RESET_BUTTON.2, SENSOR2.1 (GND), SENSOR2.5 (SDO), SENSOR2.7 (GND), SJ1.1, TP4.TP, TP5.TP, U1.4 (GND), U1.9 (EXP), U2.1 (GND), U2.28 (GND), U2.29_1 (GND), U2.29_2 (GND), U2.29_3 (GND), U2.29_4 (GND), U2.29_5 (GND), U2.29_6 (GND), U2.29_7 (GND), U2.29_8 (GND), U2.29_9 (GND), U3.13 (GND), U4.1 (CTG), U4.4 (GND), U4.6 (QSTRT), U4.9 (EP)
GPIO8: R1.2, U2.10 (IO8)
I2C_PW: R2_PINH.2, RI_PINH.2, U2.17 (IO19)
IC2_PW: C1.1, C2.1, SENSOR2.2 (CSB), SENSOR2.6 (VDDIO), SENSOR2.8 (VDD)
INT_RTC: R1_PINH1.1, TP15.TP, U2.8 (IO0), U3.3 (SQW/!INT)
IO/BOOT: BOOT_BUTTON.3, BOOT_BUTTON.4, C6.1, R_BOOT.1, U2.15 (IO9)
IO/CHANGE: C10.1, CHANGE_BUTTON.3, CHANGE_BUTTON.4, R_CHANGE.1, U2.23 (IO15)
MISO: D8.2, J4.P7 (DAT0), R8.1, TP6.TP, U1.2 (DO(IO1))
MOSI: D12.2, J1.14, J4.P3 (CMD), R7.1, TP7.TP, U1.5 (DI(IO0))
unnamed: J2.B5, R2-USB.1
unnamed: J2.A5, R2-USB1.2
unnamed: C_DELAY.1, IC1.5 (VOUT)
unnamed: EPD_C1.2, J1.4
unnamed: EPD_C2.2, J1.5
unnamed: EPD_C6.1, J1.18
unnamed: EPD_C7.1, J1.19
unnamed: EPD_C8.1, J1.20
unnamed: C4_USB.1, C5_USB.1
unnamed: EPD_C10.1, J1.22
unnamed: C1_BAT1.1, D2.1 (CATHODE), IC4.1 (VIN), IC4.3 (CE), Q1.2 (S)
unnamed: EPD_C12.1, J1.24
unnamed: D2.2 (ANODE), Q1.1 (G), R1_PWRUSB.2
unnamed: C4.2, D5.2 (A), L1.1
unnamed: C4.1, D3.2 (A), D4.1 (K)
unnamed: MCP73831.1 (STAT), R1_BAT.1
unnamed: CHG_LED.C, R1_BAT.2
unnamed: C1_BAT.1, CHG_LED.A, MCP73831.4 (VIN)
unnamed: MCP73831.5 (PROG), R2_BAT.2
unnamed: D7.1 (CATHODE), R_CAPACITOR.1
PREVGH: D5.1 (K), EPD_C9.1, J1.21
PREVGL: D4.2 (A), EPD_C11.1, J1.23
RESE: J1.3, Q3.2 (S), R3.1
RESE': SJ1.2
RESET: C5.1, IC1.1 (VIN), RESET_BUTTON.3, RESET_BUTTON.4, R_RESET.1, U2.3 (EN)
RTC_RST: U2.16 (IO18), U3.4 (!RST)
RX: TP2.TP, U2.24 (RXD0/GPIO17)
SCK: D11.2, J1.13, J4.P5 (CLK), R6.1, TP8.TP, U1.6 (CLK)
SCL: J3.4, R2_PINH.1, SENSOR2.4 (SCK), U2.20 (IO22), U3.16 (SCL), U4.7 (SCL)
SDA: J3.3, RI_PINH.1, SENSOR2.3 (SDI), U2.19 (IO21), U3.15 (SDA), U4.8 (SDA)
SRC: Q3.3 (D)
SS_SD: D6.2, J4.P2 (CD/DAT3), R10.1
TX: TP1.TP, U2.25 (TXD0/GPIO16)
USB_D+: D1.1 (I/O1_1), U2.14 (IO13)
USB_D-: D1.3 (I/O2_1), U2.13 (IO12)
VBAT: Q1.3 (D), TP3.TP, U4.2 (CELL), U4.3 (VDD)
VBBAT: C2_BAT.1, MCP73831.3 (VBAT)
VBUS: PFMF.050.1.2, TP14.TP
VRTC: C8.1, C10_SUPERCAP.1, R_CAPACITOR.2, U3.14 (VBAT)
VUSB: J2.A4, PFMF.050.1.1

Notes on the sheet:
DMG2305UX-7
USB C connector & ESD protection
SD Card
Li-Po Battery Charging Controller
ESP32 C6
Test Pads
EPD Power
Environmental Sensor BME688
Voltage Supervisor + Reset & Boot / IO Button
Battery Charge Level
SD0805S020S1R0
RTC Module DS3231SN
E-Paper Display Header
Display Type Selector
E-Paper Drive Circuit
SPI ESD Protection Lines
Owiic / Stemma QT
External NOR Flash 64MB
LDO Voltage Regulator

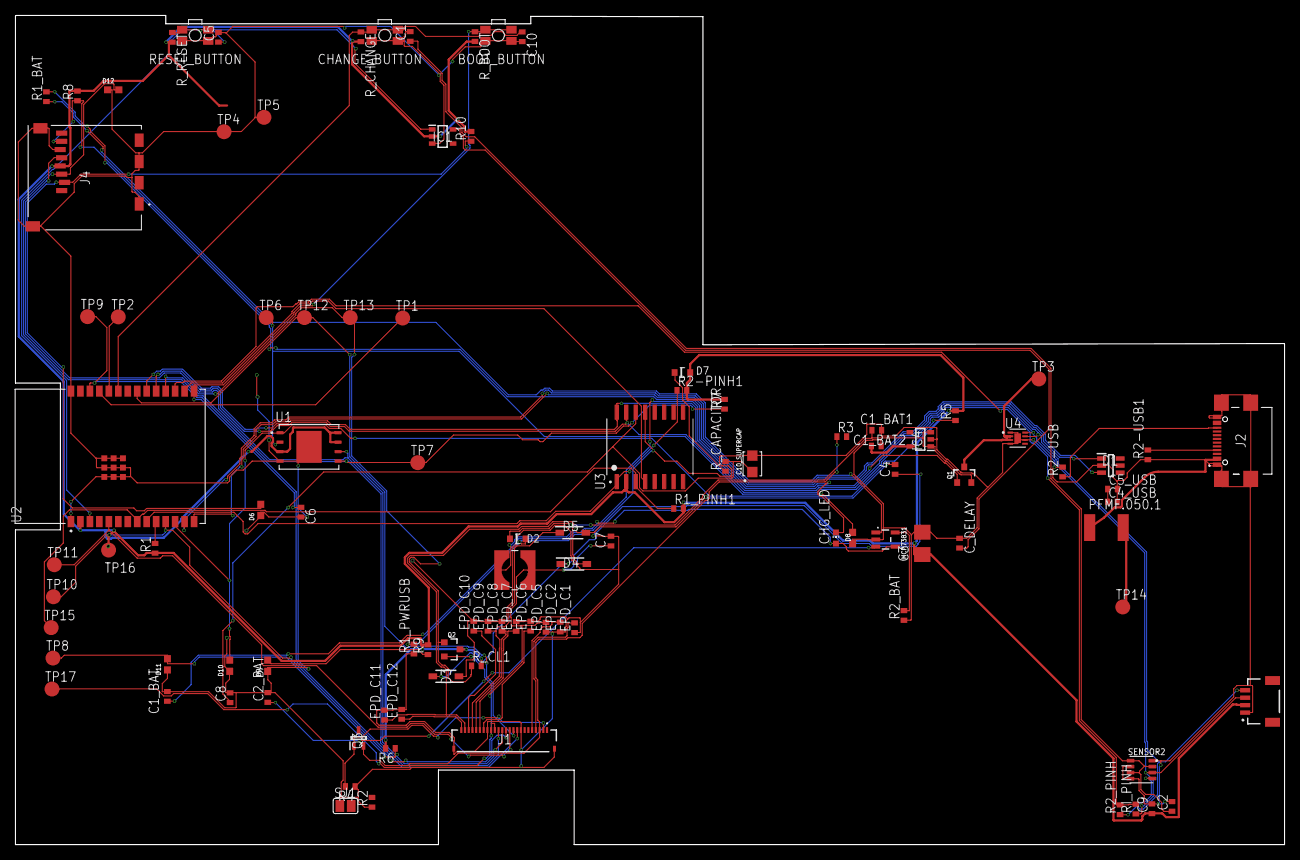
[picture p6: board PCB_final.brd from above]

Board: 2 copper layers, 170.2 x 111.2 mm, 103 parts (0 on the bottom side), 58 nets.

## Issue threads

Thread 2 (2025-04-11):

Schematic Issue

CristiPetrisor, 2025-04-11:
Titlurile chenarelor nu sunt poziționate ca in imaginea cu schematicul. Majoritatea sunt poziționate in stângă sus. Si legat de aspect, dimensiunile ar trebui sa fie relativ egale.

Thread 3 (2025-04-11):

Schematic Issue - 2

CristiPetrisor, 2025-04-11:
Label-urile au dimensiuni diferite. Pentru aspectul complet al proiectului, recomand sa aibă aceeași dimensiune.

Closed 2025-04-14.

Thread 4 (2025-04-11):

PCB - Issue

CristiPetrisor, 2025-04-11:
In PCB, trebuie sa rezolvi acele GAP-uri, ma refer la faptul ca trebuie sa se facă GND pour acolo.

Closed 2025-04-14.

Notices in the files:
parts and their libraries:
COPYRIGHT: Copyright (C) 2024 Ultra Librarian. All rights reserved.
